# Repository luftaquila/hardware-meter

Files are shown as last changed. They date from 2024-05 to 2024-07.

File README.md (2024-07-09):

# hardware-meter

`hardware-meter` is a classical analog gauge that shows a hardware usage. It is a simple analog voltmeter with a microprocessor. Any MCU with USB serial communication and PWM GPIO could be used.

https://github.com/luftaquila/hardware-meter/assets/17094868/05a8670c-ace7-459e-b40a-1173809b3f6e

Supported OS:

* Windows
* MacOS
* Linux (Not tested yet)

Supported metrics:

* CPU Utilization
* CPU Frequency
* Memory Utilization
* Swap Utilization
* Networks Speed

CPU temperature, disk metrics and GPU metrics will supported in the future.

Any MCUs like Arduino(ATmega), STM32 and ESP32 with USB and PWM could be used.

## Prerequisites
* Any MCU with USB serial and PWM output
* An analog voltmeter
  
> [!NOTE]
> Arduino(ATmega) must have `u#` in its chip name (ex. ATmega32u4), which means on-chip USB support.
> <br><br>
> STM32 series have too many variants to explain here. Take a look at their catalog and choose a chip with USB peripheral.\
> Provided firmwares are for `STM32F103C8T6` and `STM32F407VET6`.
> <br><br>
> On ESP32 series, `ESP32-S2`, `ESP32-S3`, `ESP32-C3`, `ESP32-C6`, `ESP32-H4` are supported.\
> Plain `ESP32` and `ESP32-C2` is not supported since there is no USB peripheral. 

> [!TIP]
> There are common analog panel meters called `85C1` and `91C4` series, which cost only $2~3 and have a various voltage range. There are 0-3V and 0-5V models, which fit with most common MCUs.
> <br><br>
> Choose a voltage range by your MCU's logic level. 5V MCUs such as Arduino can manipulate both 0-5V and 0-3V models. 3.3V MCUs such as ESP32 or STM32, Raspberry Pi, etc. can only run 0-3V models.

### Reminder
If you write your own MCU code instead of using provided firmwares, please read followings carefully:

> [!IMPORTANT]  
> If you are using a 5V MCU with a 0-3V voltmeter, the PWM output ***must*** be regulated to 3V max. If your MCU is 3.3V, it is recommended to adjust the PWM voltage to a max 3V, not 3.3V.

> [!IMPORTANT]  
> If you use a 0-5V range voltmeter, please keep in mind that the PWM output voltage could be lower than 5V depending on your PC and MCU.\
> If your PC supplies a voltage less than 5V to the MCU via the USB, the MCU can only output that voltage to its PWM pin.
> Also, most MCUs have a protection diode on their USB input, which makes additional VCC voltage drop. Mostly 0.3V (Schottky diode) or 0.7V (general diode).\
> This will result in the analog gauge not pointing its max position, even if the metric is pointing 100%. For example, if your PC supplies 4.7V and a protection diode drops 0.7V, the gauge will point 4V position even if the CPU is in full load.

## DIY!
1. Connect the voltmeter and the MCU. Test your voltmeter's polarity with some batteries before connect with MCU.
    * `+` terminal goes to the PWM supported GPIO pin, and `-` terminal goes to the GND.
3. Upload a firmware in [`devices/*`](https://github.com/luftaquila/hardware-meter/tree/main/devices) to your MCU.

|Supported MCU|PWM pin|Voltmeter<br>range|Note|Implementation|
|:-:|:-:|:-:|:-:|:-:|
|Arduino|D3|0-5V|Arduino IDE project (*.ino)|[4255dcc](https://github.com/luftaquila/hardware-meter/commit/4255dcc31e8221ad6f17f32b5cbf0cf269fe91b5)|
|STM32F4|PA8|0-3V|STM32CubeIDE project<br>(`STM32F407VET6`)|[7c3e3a1](https://github.com/luftaquila/hardware-meter/commit/7c3e3a1a7421477c3b945049cbb990eb700c9f11)|
|STM32F1|PA8|0-3V|STM32CubeIDE project<br>(`STM32F103C8T6`)|[265403c](https://github.com/luftaquila/hardware-meter/commit/265403c16b42c878c83aad94794e0df8ea754b39)|

> [!NOTE]
> If there is no firmware for your MCU, please implement and contribute your own!
> <br>
> It is just a basic program that reads 4 bytes little-endian float value from the serial and makes corresponding PWM output.

Optional:
* Build a 3d printed housing with 3d models at [`3d models/*`](https://github.com/luftaquila/hardware-meter/tree/main/3d%20models)

## Run
1. Download a latest desktop program at [Releases](https://github.com/luftaquila/hardware-meter/releases).
2. Connect your MCU and PC with a USB cable.
3. Run your desktop executable. The tray icon will be generated.
4. Click the tray icon and select your MCU's serial port.

> [!NOTE]
> The list of the ports will be only scanned at the program launch.
> <br>
> This is a limit of [tray-item-rs](https://github.com/olback/tray-item-rs) as their tray items are not editable or removable.

> [!TIP]
> You can build a desktop program on your own by running `cargo build --release`.

## More
If you are good at soldering, something like this is possible:



This is a `hardware-meter` with a USB Type-C port. All components including MCU and the Type-C port is mounted inside voltmeter.

The [Arduino Pico](https://projecthub.arduino.cc/MellBell/arduino-pico-the-worlds-smallest-arduino-board-bc7986) runs 0-5V 85C1 voltmeter. USB Micro port on the Pico is desoldered and jumped onto a DIY Type-C board at the back side.

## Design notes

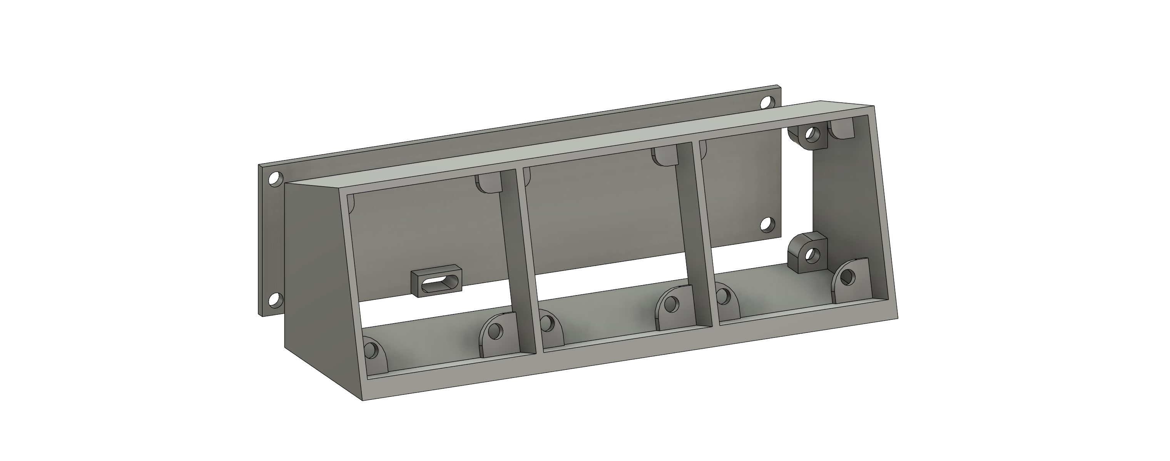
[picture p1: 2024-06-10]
3d models/91c4-housing-3x/91c4-housing-3x.png

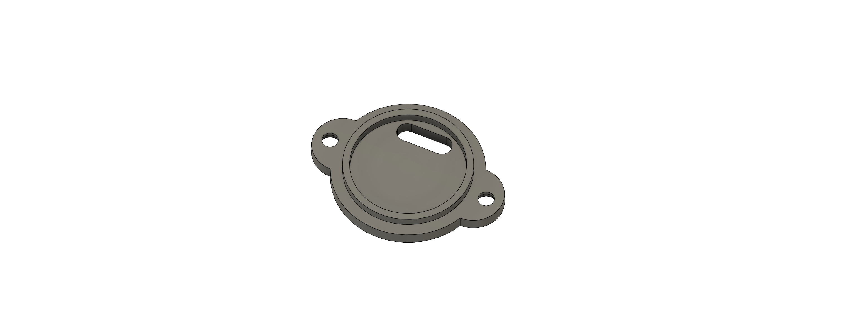
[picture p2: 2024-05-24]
3d models/85c1-back-cover-type-c/85c1-back-cover-type-c.png

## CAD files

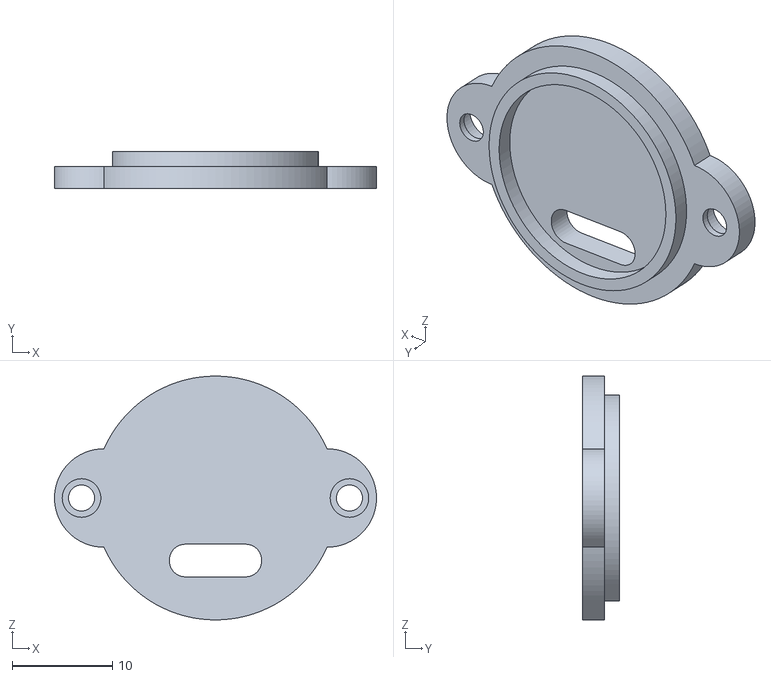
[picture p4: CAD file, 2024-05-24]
3d models/85c1-back-cover-type-c/85c1-back-cover-type-c.stl
32.1 x 3.70 x 24.3

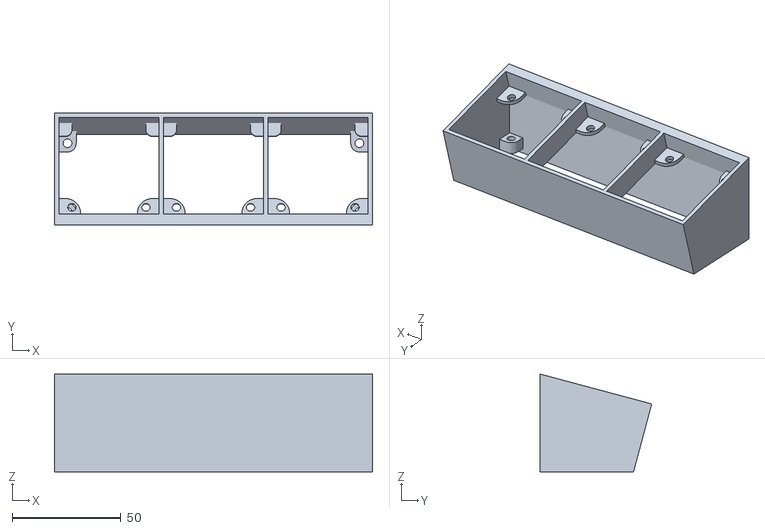
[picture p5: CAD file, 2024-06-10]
3d models/91c4-housing-3x/91c4-housing-3x.stl
146.0 x 51.2 x 44.9

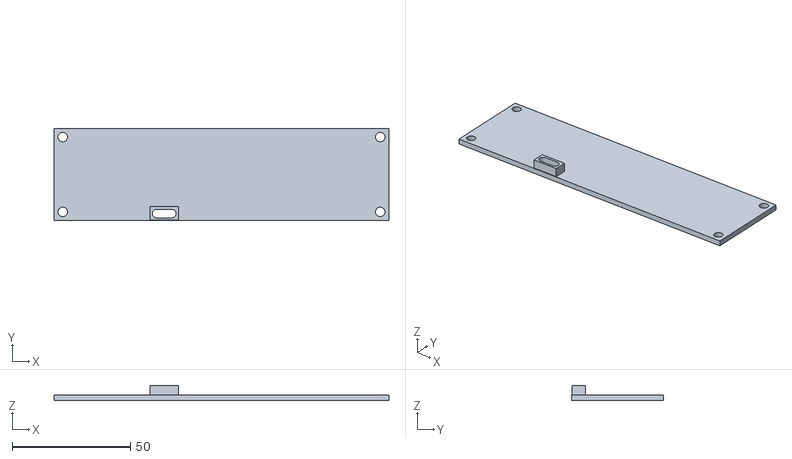
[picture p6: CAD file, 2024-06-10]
3d models/91c4-housing-3x/91c4-housing-3x-cover.stl
141.4 x 39.0 x 6.40

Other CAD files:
3d models/85c1-back-cover-type-c/85c1-back-cover-type-c.f3d
3d models/91c4-housing-3x/91c4-housing-3x.f3d

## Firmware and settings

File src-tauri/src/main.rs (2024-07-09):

#![cfg_attr(not(debug_assertions), windows_subsystem = "windows")]

mod command;
mod common;
mod serial;

use std::{fs, sync::mpsc, thread};

use notify::RecursiveMode;
use notify_debouncer_mini::new_debouncer;
use tauri::Manager;
use tauri::{CustomMenuItem, SystemTray, SystemTrayEvent, SystemTrayMenu, SystemTrayMenuItem};

use crate::{
    command::{
        config, get_channel_count, get_config, get_core_count, get_gauge_types, get_netifs,
        get_ports, get_speed_units, open_config_dir,
    },
    common::ConfigFile,
    serial::serial_thread,
};

fn main() {
    let mut config_exists = false;
    let (tx, rx) = mpsc::channel();

    /* create config file monitor */
    fs::create_dir_all(ConfigFile::dir()).unwrap();

    let ctx = tx.clone();
    let (etx, erx) = mpsc::channel();
    let mut debouncer = new_debouncer(std::time::Duration::from_millis(100), etx).unwrap();

    debouncer
        .watcher()
        .watch(&ConfigFile::dir(), RecursiveMode::NonRecursive)
        .unwrap();

    thread::spawn(move || {
        for result in erx {
            match result {
                Ok(events) => events.iter().for_each(|event| {
                    if event.path == ConfigFile::path() {
                        if let Ok(file) = ConfigFile::from_json() {
                            ctx.send(file).unwrap();
                        }
                    }
                }),
                Err(_e) => {
                    // !TODO: error handling
                }
            }
        }
    });

    /* create serial port thread */
    thread::spawn(move || serial_thread(rx));

    /* use previous config file if exists */
    if let Ok(file) = ConfigFile::from_json() {
        config_exists = true;
        tx.send(file).unwrap();
    }

    /* set system tray menu */
    let tray_menu = SystemTrayMenu::new()
        .add_item(CustomMenuItem::new("about".to_string(), "About"))
        .add_native_item(SystemTrayMenuItem::Separator)
        .add_item(CustomMenuItem::new("settings".to_string(), "Settings"))
        .add_native_item(SystemTrayMenuItem::Separator)
        .add_item(CustomMenuItem::new("quit".to_string(), "Quit"));

    tauri::Builder::default()
        .system_tray(SystemTray::new().with_menu(tray_menu))
        .on_system_tray_event(|app, event| match event {
            SystemTrayEvent::LeftClick {
                position: _,
                size: _,
                ..
            } => {
                app.get_window("main").unwrap().show().unwrap();
            }
            SystemTrayEvent::MenuItemClick { id, .. } => match id.as_str() {
                "about" => {
                    open::that("https://github.com/luftaquila/hardware-meter").unwrap();
                }
                "settings" => {
                    app.get_window("main").unwrap().show().unwrap();
                }
                "quit" => {
                    std::process::exit(0);
                }
                _ => {}
            },
            _ => {}
        })
        .on_window_event(|event| match event.event() {
            tauri::WindowEvent::CloseRequested { api, .. } => {
                event.window().hide().unwrap();
                api.prevent_close();
            }
            _ => {}
        })
        .invoke_handler(tauri::generate_handler![
            config,
            get_config,
            get_core_count,
            get_channel_count,
            get_gauge_types,
            get_netifs,
            get_speed_units,
            get_ports,
            open_config_dir
        ])
        .build(tauri::generate_context!())
        .expect("error while building tauri application")
        .run(move |app, event| match event {
            tauri::RunEvent::Ready => {
                // show settings on launch only if there is no valid config file
                if !config_exists {
                    app.get_window("main").unwrap().show().unwrap();
                }
            }
            tauri::RunEvent::ExitRequested { api, .. } => {
                api.prevent_exit();
            }
            _ => {}
        });
}

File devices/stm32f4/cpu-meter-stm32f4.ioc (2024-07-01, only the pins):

Mcu.UserName=STM32F407VETx
PA11.Signal=USB_OTG_FS_DM
PA12.Signal=USB_OTG_FS_DP
PA8.Signal=S_TIM1_CH1
PC6.Signal=S_TIM8_CH1
PC7.Signal=S_TIM8_CH2
PC8.Signal=S_TIM8_CH3
PC9.Signal=S_TIM8_CH4
PE11.Signal=S_TIM1_CH2
PE13.Signal=S_TIM1_CH3
PE14.Signal=S_TIM1_CH4
PH0-OSC_IN.Signal=RCC_OSC_IN
PH1-OSC_OUT.Signal=RCC_OSC_OUT

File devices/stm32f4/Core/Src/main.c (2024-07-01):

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
/* Includes ------------------------------------------------------------------*/
#include "main.h"
#include "tim.h"
#include "usb_device.h"
#include "gpio.h"


void SystemClock_Config(void);
/**
  * @brief  The application entry point.
  * @retval int
  */
int main(void)
{

  /* MCU Configuration--------------------------------------------------------*/

  /* Reset of all peripherals, Initializes the Flash interface and the Systick. */
  HAL_Init();

  /* Configure the system clock */
  SystemClock_Config();

  /* Initialize all configured peripherals */
  MX_GPIO_Init();
  MX_TIM1_Init();
  MX_USB_DEVICE_Init();
  MX_TIM8_Init();
  /* USER CODE BEGIN 2 */
  HAL_TIM_PWM_Start(&htim1, TIM_CHANNEL_1);
  HAL_TIM_PWM_Start(&htim1, TIM_CHANNEL_2);
  HAL_TIM_PWM_Start(&htim1, TIM_CHANNEL_3);
  HAL_TIM_PWM_Start(&htim1, TIM_CHANNEL_4);
  HAL_TIM_PWM_Start(&htim8, TIM_CHANNEL_1);
  HAL_TIM_PWM_Start(&htim8, TIM_CHANNEL_2);
  HAL_TIM_PWM_Start(&htim8, TIM_CHANNEL_3);
  HAL_TIM_PWM_Start(&htim8, TIM_CHANNEL_4);
  /* USER CODE END 2 */

  /* Infinite loop */
  /* USER CODE BEGIN WHILE */
  while (1)
  {
    /* USER CODE END WHILE */

    /* USER CODE BEGIN 3 */
  }
  /* USER CODE END 3 */
}

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


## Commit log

2024-05-09 add: arduino support
2024-05-23 improve: recover from serial port failure
    [main.rs]
2024-05-23 fix: tray icon per platform
    [main.rs]
2024-05-24 add: 85c1 back cover 3d model
    [85c1-back-cover-type-c.f3d, 85c1-back-cover-type-c.stl]
2024-05-24 fix: build on linux
    [main.rs]
2024-05-26 add: initial stm32f4 STM32CubeIDE project
2024-05-26 add: STM32F4 support
2024-05-26 update: exit on port open failure, not panic
    [main.rs]
2024-05-27 add: stm32f103 initial code
2024-05-27 add: stm32f1 support
2024-05-27 update: add stm32f1 support on readme
2024-05-27 fix: prev port save and port open error handling
    [main.rs]
2024-06-10 add: 3x 91c4 housing 3d model
    add: 91c4-housing-3x
    [91c4-housing-3x-cover.stl, 91c4-housing-3x.f3d, 91c4-housing-3x.stl]
2024-06-10 update: stm32f1 pwm channels activation
2024-06-11 add: gitignore STM32CubeIDE build directories
2024-06-14 update: channel support for arduino
2024-07-01 update: set ioc makefile project and improve pwm output selection
2024-07-01 fix: stm32f1 tim2 frequency
    [cpu-meter-stm32f1.ioc]
2024-07-01 fix: USB VID and timer configurations
    [cpu-meter-stm32f1.ioc, cpu-meter-stm32f4.ioc, main.c]
2024-07-01 update: stm32f4 implementation
2024-07-01 update: arduino implementation
2024-07-02 feature: gui prototype with tauri
2024-07-07 add: master switch
2024-07-09 update: file event watch thread
2024-07-09 fix: rust build warnings
    [main.rs]
2024-07-09 fix: local config directory creation
    [main.rs]

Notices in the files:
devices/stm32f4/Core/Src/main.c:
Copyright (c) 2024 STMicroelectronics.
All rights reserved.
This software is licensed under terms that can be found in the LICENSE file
